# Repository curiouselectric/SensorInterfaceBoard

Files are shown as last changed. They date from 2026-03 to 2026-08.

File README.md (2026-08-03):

# Sensor Interface Board

A unit to interface various sensors (digital/analog/RS485) with a simple serial interface via an ATMega328-based circuit. The unit also provides averaged data, controlled stepped-up supply voltage and a field-adjustable ID.

"Why do you need that?", you ask.... 

I had been wanting to use an industrial soil mositure sensor for a simple project. This device was only available as an RS3485 device. So I ordered that - it then took days of head scratching to sort basic communication with the device. This unit is meant to simplify reading of avaeraged data from RS485 sensors and make it easy to get that data into your project via a simple serial request/reply set of commands.

The other issue with a lot of the RS485 sensor is that they need higher voltages supplied (such as 12V or even 24V DC). So on this interface board I added a DC-DC step up converter to power the sensor. 

I was also concerned with energy consumption (my project was battery based). If I was to leave the DC-DC converter running all the time then my battery would run down very quickly. So I added control of the power to the sensor, so that I can power up, take the readings then power down. This saves a huge ammount of energy (well, proportional to my battery size).

## Overview

The problem with measuring sensors with values that change relatively quickly is that they constantly need to be checked. This requires a bit of microcontroller time and processing. This unit is designed to solve that.

Wire up your RS485 sensor. Power the unit up. Then it will save the averaged data for you. You can then get hold of the data through serial requests and process as you need.

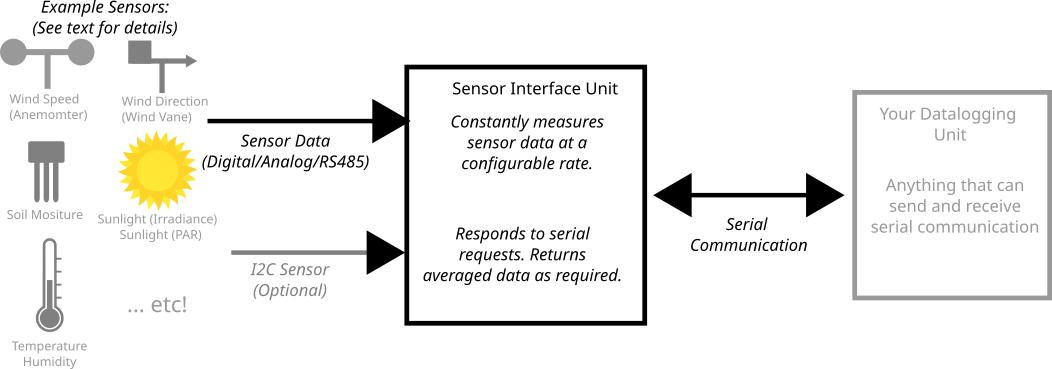
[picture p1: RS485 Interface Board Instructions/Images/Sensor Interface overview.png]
Overview


I wrote this to interface to an ESP32 data logger, which sleeps most of the time. It wakes up, talks to the RS485 sensor, gets the data it needs, then goes back to sleep, knowing the RS485 Interface Board is always monitoring.

It was designed as a relatively simple interface to remove the need for monitoring pulses/dealing with RS485 requests/getting sensor data and averaging the sensor data.

The brilliant [ESPHome project](https://esphome.io/components/#environmental) has loads of sensor types you can interafce easily with a low cost ESP microcontrollers. For systems that have WiFi and good power connections then that project is a good resource to use. This project is designed for very low power systems (battery based datalogging) and for situations where easy access to Wi-Fi is not available.

There are two mode of operation, depending upon your use case:

## Response Mode

In this mode then the unit responds to serial requests made. You ask the sensor for data and this is returned. It never sends anything unless asked.

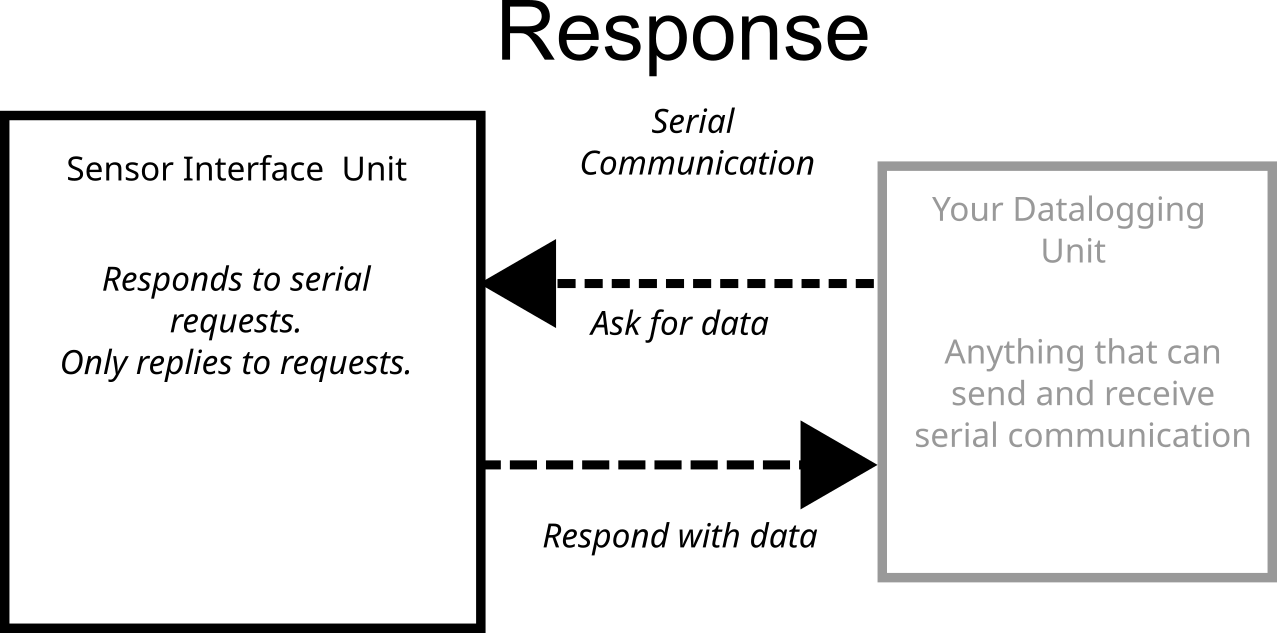
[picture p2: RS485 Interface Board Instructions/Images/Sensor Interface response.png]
Response


## Broadcast Mode

In this mode then the unit regularly sends data via the serial connunication. It will send the averaged data for (0) 1 second, (1) 10 second, (2) 1 min, (3) 10 min and (4) 1 hour averaged data. If this is set to (5) then the unit does not send any data. The send mode is stored in EEPROM, so it will start sending data again even if power is lost.

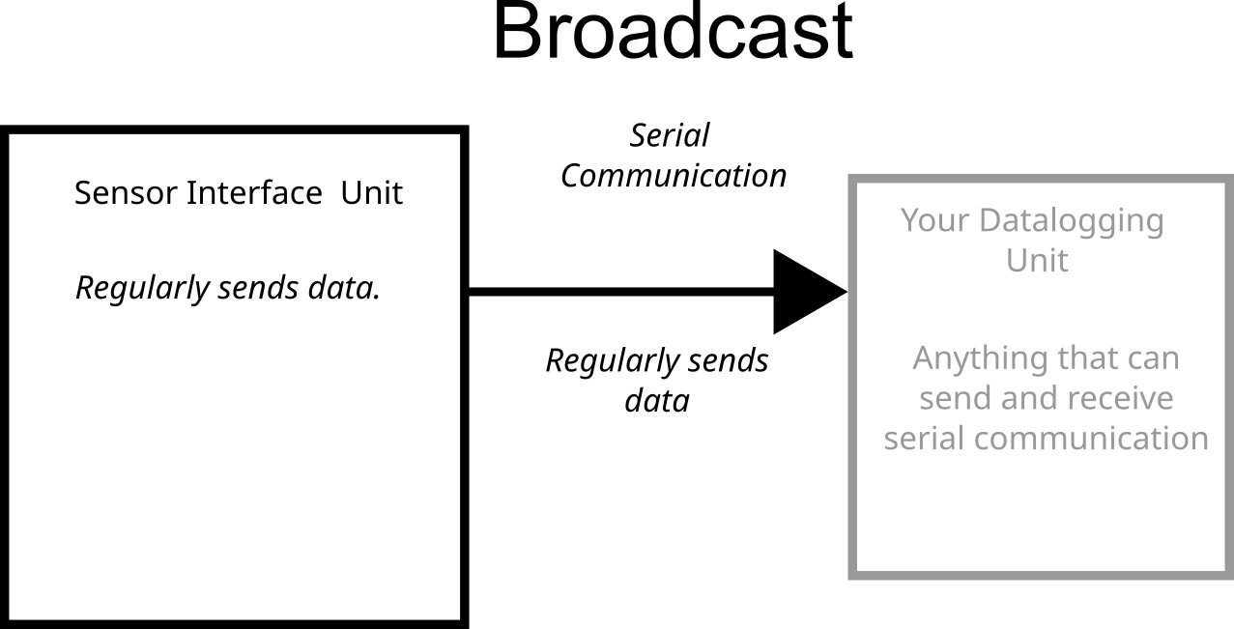
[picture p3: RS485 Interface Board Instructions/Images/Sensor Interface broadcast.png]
Broadcast


Boradcast mode works well if the logger is always listening and you only have one sensor in range. If more than one sensor is in range then the data will clash and potentially cause issues, in which case use Response mode.

The two modes work together - you can have the unit sending regular data and also responding to requests.

It runs on an ATMega328 running at 16MHz with selectable baud serial (up to 57600). It comes pre-programmed, but new code can be uploaded via the Arduino IDE, with the Uno bootloader. See firmware for more details.

## Sensor Types

There are a huge range of RS485 sensors for many different variables. I'd like this unit to be adaptable to work with a variety of sensors with minimal code changes.

This code base also works with other, non-RS485 sensors, such as wind speed sensors, wind vanes and solar irradiance sensors.

## Sensors Implemented:
This is a list of the sensor types which have been implemented with this software, Along with the version number they were added.

Sensor Name                        |  Ref    |  Version | Device Type  |   ID                   | Link                                                 | Notes  |
-----------------------------------|---------|----------|--------------|------------------------|------------------------------------------------------|--------|
Soil Temperature & Humidity        |ZTS-3000 |1.0       | SM           |ZTS-3000-TR-WS-N01     |[https://www.curiouselectric.co.uk/products/soil-moisture-sensor](https://www.curiouselectric.co.uk/products/soil-moisture-sensor) |     |
Wind Sensor (speed & direction)    |         |1.3       | WT           |                         |[https://www.curiouselectric.co.uk/collections/monitoring/products/wind-sensor-interface](https://www.curiouselectric.co.uk/collections/monitoring/products/wind-sensor-interface)  | Works with Anemometer and Wind Vane | 
RS485 Pyranometer Irradiance Sensor| PYR20    |1.4         | PY           |PYR20              |[https://www.aliexpress.com/item/1005002999915991.html](https://www.aliexpress.com/item/1005002999915991.html) |              |
DIY Irradiance Sensor              |         |          | IR           |                |     |     |
PAR Sensor                         |         |          | PR           |                |     |     |
Air Temperature/Humidity/Pressure  |         |1.3       | not needed    |AHT20 / BMP280 | [https://www.aliexpress.com/item/1005004460907148.html](https://www.aliexpress.com/item/1005004460907148.html) | This adds onto the PCB along with a sensor above|

# Hardware

A number of PCBs have been designed in KiCAD. This repository holds the RS485 sensor and is available here. A small PCB has been designed.

There is one reset switch, one user input switch and one LED output. 

There is a step-up DC-DC converter with power control (to power higher voltage sensors). 

There is a TTL to RS485 converter (to connect to the RS485 sensors)

There is a 4 pin 'Grove'-type connector for direct connection I2C (code for this is not yet implemented) 

## Board ID Number

Each unit can have a unique ID (using a push link 6 pin pad for 0-7 values), so multiple units can be added to a serial bus, if needed. The defalt is 0 (no links used).

## PCB User Switch and User LED

There is one user switch and one user LED on the unit.

The LED will show a regular flash every 5 seconds. This will briefly flash once every 5 seconds if the unit is in 'Response' mode. The LED will briefly flash twice every 5 seconds if the unit is in 'Broadcast' mode. Data will be sent at the broadcast rate.

The LED will also flash whenever data is sent of the serial port. The LED will go on before data sent and then off after data is sent.

Pressing the user switch for >0.5 seconds and then releasing will result in a switch press.

A switch press will increment the mode from 0-1-2-3-4-5 then back to 0.

The unit will flash after a button press to indicate the broadcast mode (so 0 flashes if the value is 0, 1 flash if the value is 1 etc).

If this is set to 5 then the unit works in 'Response' mode.

If this is set to 0-4 then the unit is in 'Broadcast' mode and will send the data at the relevant interval (0 = 1s, 1 = 10s, 2 = 1 min, 3 = 10 min and 4 = 1 hour).

The mode can also be set with a serial request, using the "Set the unit to broadcast:" method (see below).

# Firmware

This uses an ATMega328 with the MiniCore Bootloader. This uses an oscillator running at 16MHz for 5V supply or 8MHz for 3.3V supply. Check the correct oscillator is chosen when uploading.

## Initial bootloader installation:

You should not need to do this, as the unit should come with this already installed. This is just for information.

To upload a bootloader it then MiniCore is used:

Install MiniCore from here: https://github.com/MCUdude/MiniCore

Install the bootloader using an Arduino as an ISP. https://www.arduino.cc/en/Tutorial/BuiltInExamples/ArduinoISP

Wire up your arduino and an ISP 3x2 header pin onto the wind sensor PCB.

Choose the "ATMega328" option with the "External 8MHz Oscillator" set for the 3.3V version or "External 16MHz Oscillator" set for the 5V version, depending upon the crystal supplied.

The ATmega328 datasheet says that an 8MHz crystal should be used at 3.3V for reliable serial comms. YMMV. 

You can then use the 'Burn Bootloader' option within 'Tools' in the Arduino IDE. This will install the Minicore bootloader.

## Program via Arduino IDE

You can only do this when the bootloader is programmed (this will be programmed for versions supplied by me).

To program it then MiniCore is used:

Install MiniCore from here: https://github.com/MCUdude/MiniCore

Add to preferences and then board manager.

Choose the "ATMega328" option with the "External 8MHz Oscillator" set for the 3.3V version or "External 16MHz Oscillator" set for the 5V version, depending upon the crystal supplied.

The ATmega328 datasheet says that an 8MHz crystal should be used at 3.3V for reliable serial comms. YMMV. 

You can then upload code using the 6pin serial/FTDI interface on the board.

# Serial Data and Commands

It returns the average values and information when requested on serial port.

If the 8-bit CRC (Cyclic Redundancy Check) is used then each request must have a 2 char CRC added between the ? and # within these commands (labelled ^^ here).
For the responses, if no CRC enabled then the ?^^ within these commands is NOT returned. You must use the ? for a command, but the response will not contain it.

At all other times then the unit is asleep.

## Set the unit to broadcast:

Request: "aaI0SEND*?^^#" where * is an int (0)= 1s data, (1)= 10s data, (2)= 60s/1 min data, (3)= 600s/10 min data, (4)= 3600s/1hr data, (5)= NO data

Returns: "aaI0SEND*?^^#" + CRC if requested where * is an int (0)= 1s data, (1)= 10s data, (2)= 60s/1 min data, (3)= 600s/10 min data, (4)= 3600s/1hr data, (5)= NO data

You can also set the unit to broadcast using the user switch. Press the button for around 0.5s or more then release. This will go through the boradcast modes from 0-1-2-3-4-5 then back round to 0. The LED will flash the number of times for the setting (so send = 0 the unit will not flash, but data will appear within 1 second!).

If the unit is in broadcast mode then the minimum and maximum wind speeds and the wind vane data are all reset each time period.

## What is baud rate?:

Request: "aaI0BD?#" ("aaI0BD?dc#" with CRC)

Returns: "aI0BD9600?^^#"  // Where 9600 is the baud rate 

## Set Baud Rate:

Request: "aaI0STBD\*?^^#"  Where \* is (0)1200, (1)2400, (2)9600, (3)57600, (4)115200

Returns: "aaI0BD9600?^^#"   // Where 9600 is the baud rate + CRC if requested

## What is ID?:

Mentioned at start up of unit - it is hardware set... and cannot be changed in code.

ID selection is by using a shorting link on the pads labelled 1, 2 and 4. The default is for no pads to be connected and the ID is 0. This means the unit will respond to "I0" as the ID.

To change the ID to another number from 0-7 then use a shorting link on the pins to create a binay number. The connections are:

1    |2    |4     | ID
-------|-------|-------|----
NC     |NC     |NC     | 0
CONN |NC     |NC     | 1
NC     |CONN |NC     | 2
CONN |CONN |NC     | 3
NC     |NC     |CONN | 4
CONN |NC     |CONN | 5
NC     |CONN |CONN | 6
CONN |CONN |CONN | 7

You can request the ID:

Request: "aaI*ID?^^#"  The * value can be anything.

Returns: "aaIXID:X?^^#"   // Where X is the device ID + CRC if requested

## Request Data from ONE channel

Request: “aaI0R00A*?^^#” where 00 is the channel number (00, 01 etc) and * is the averaging period (* = 0 for 1 sec data, 1 for 10 sec data, 2 for 60 sec (1 min) data, 3 for 600 sec (10 min) data and 4 for 3600 sec (1 hr) data 

Returns:  "aaI0R00A*:123.40:123.40:123.40?^^#"  // This wil return the average data then : then the minimum value then : then the maxximum value.

## Request Data from ALL channels

Request: “aaI0RAAA3?^^#”

Returns: "aaI0RAAA1:123.40:567.80?^^#" where the first item of data is channel 0, the next is channel 1. This will depend upon the number of channels.

## Request ALL Minimum data

Request: “aaI0RMNA4?^^#”  - does not matter what averaging period. min/max are just the min/max seen at max data rate.

Returns: "aaI0RMN:123.40:567.80?^^#"  where the first item of data is channel 0, the next is channel 1. This will depend upon the number of channels.

## Request ALL Maximum data

Request: “aaI0RMXA0?^^#”  - does not matter what averaging period. min/max are just the min/max seen at max data rate.

Returns: "aaI0RMX:123.40:567.80?^^#"  where the first item of data is channel 0, the next is channel 1. This will depend upon the number of channels.

## Reset the Min and Max value:

The min and max of each channel are logged. These are reset if the data is sent in broadcast mode. If the unit is in Response mode then you need to reset the min/max when you have taken the data.

Request: "aaI0RESET?#" ("aaI0RESET?d9#" with CRC)

Returns: "aaI0RSTOK#"

## Request Temperature, Humidity and Pressure Data

This command can only be used if the I2C AHT20/BMP280 sensor is attached and has been defined in the code. Otherwise it will return an error.

You can call this at any time and the unit will request from the sensor. It is NOT averaged or requested at any other point.

The Temp and Humidity board is an AHT20 (with device ID 0x38) and a BMP280 is used to measure the air pressure (with device ID 0x77).

Request: "aaI0TEMP?^^#"  (^^ for the CRC)

Returns: "aaI0T$$.$$H$$.$P$$$$$$?^^#" (^^ for the CRC) and $$$ are the values (floats) for Temeprature in C and Reltive Humidity in % and Air Pressure in Pa.
Returns: "aaI0T-H-P-#" if the board is not connected or there is an issue wth one of the sensors.

## Serial 'Button' press

You can simulate a button press with a serial command. This might be useful for some logging applications

The command "aaI0SWA?^^#"  (Where ^^ is the CRC of the data before the ?) will act just like a button press. This is for control via a data logger serial port without access to the physical switch.

Request: "aaI0SWA?^^#" 

Returns: "aaSEND*?^^#", where * is the time interval to send data (0->1->2->3->4->5->0 etc, with 5 never sending)

## What is the software version?:

Request: "aaI0SWV?^^#"

Returns: "aaI0SWV:1.0?^^#" (where 1.0 is the software version)

## What is the device type?:

Request: "aaI0DT?^^#""

Returns: "aaI0DT:SM?^^#" where SM is the device type (SM = Soil Moisture) - check the sensor list for these 2 char codes.

## Add CRC check:

Within the config of the firmware a CRC (Cyclic Redundancy Check) can be added to the data (or not!).

Set this true using the flag in the config.h file:

  #define ADD\_CRC\_CHECK     true    // Use this to add CRC check to incomming and outgoing messages
  
This uses the CRC routines from Rob Tillaart, available here: https://github.com/RobTillaart/CRC

A 'CRC-8/SMBUS' is perfromed on the data and a 2 byte CRC code is added to all replys (and expected on all enquiries). This is added between a ? and # symbol.

If no CRC then the end char is a #.

For example: aaI0RESET?d9# has the CRC check d9 added to the reset request.

Remember: Capitalisation will affect the results: D is not the same as d!

You can use this online calculator to check your CRC: https://crccalc.com/ The type of CRC is CRC-8/SMBUS.

## Failure codes:

If data is not that length or does not have 'aa' and '#' at start/end then return with send "aaFAIL\*\*#" error code. All will have CRC on these codes, if requested.

+ "aaFAILCRC?^^#": CRC check fail
+  "aaFAILTL?^^#": String too long
+  "aaFAILID?^^#": Problem with ID
+  "aaFAILIDX?^^#": ID not correct to device
+  "aaFAILPE?^^#": No aa and # on the string
+  "aaFAILBD?^^#": Baud rate change fail
+  "aaFAILCN?^^#": Channel number requested is greater than channels existing
+  "aaFAILCMD?^^#": Command not recognised 

# Sensor Specific Commands
For each sensor type there are additional commands. These are only available if the unit is in the correct mode.
They are listed here.

## 'SM' RS485 Soil Mositure Sensor

There are no extra commands.

## 'PY' RS485 Pyranometer Irradiance Sensor

There are no extra commands.

## 'WS' Wind Speed Sensor (Vane and Anemometer)

### Wind Speed data:

Request: “aaI0WSA4#”  ("aaI0WSA4?19#" with CRC)  Where 0 is an ID from 0-7 set by solder on PCB. 4 is the averaging period (0=1s, 1=10s, 2 = 60s, 3 = 600s, 4=3600s)

Returns: "aaI0WSA4:3.00:5.67:1.23#"  // Where 4 is the averaging period, 3.00 is the data within the averaging period, 5.67 is the maximum and 1.23 is the minimum.

### Wind Speed data minimum:

Request: “aaI0RMN#” ("aaI0RMN?^^#" with CRC) - does not matter what averaging period. min/max are just the min/max seen.

Returns: "aaI0RMN:3.00#"  // Where 3.00 is the data + CRC if requested

### Wind Speed data maximum:

Request: “aaI0RMX#”  ("aaI0RMX?^^#" with CRC) - does not matter what averaging period. min/max are just the min/max seen.

Returns: "aaI0RMX:3.00#"  // Where 3.00 is the data + CRC if requested

### What is Anemometer conversion?:

Request: "aaI0WSCON#" ("aaI0WSCON?41#" with CRC)

Returns: "aaI0STWSCONm123.4c567.89#" (from stored values) + CRC if requested

### Set the Anemometer conversion:

Request: "aaI0WSSTm123.4c567.89#"  ("aaI0WSSTm123.4c567.89?38#" with CRC) Where 123.4 is the gradient and 567.89 is the constant (y=mx+c)

Returns: "aaI0STWSSETm123.4c567.89#" (set to the new values) + CRC if requested

Request: "aaI0WSSTm1c0#" or "aaI0WSSTm1c0?da#" with CRC to set m= 1 and c=0. This is useful for initial testing.

### Wind Vane data:

Request: “aaI0WV#”  ("aaI0WV?b4#" with CRC) Where 0 is an ID from 0-7 set by solder on PCB.

Returns:    The instantaneuous direction AND the direction array data

Returns:    "aaI0WV=W:0.00:0.00:0.00:0.00:0.00:0.00:62.00:0.00#" + CRC if requested

### Reset the max, min and wind vane array:

Request: "aaI0RESET#" ("aaI0RESET?d9#" with CRC)

Returns: "aaRESET#"

### Enter vane training mode:

Request: "aaI0VT?#" ("aaI0VT?af#" with CRC) OR long press of the button (>1 second) will enter this mode.

Returns: Enter the vane training routine - use button to go through the different directions and set the values.

The serial port will show which direction the vane should be pointing at.

Move the vane to this position and press the user switch (for around 0.5 seconds).

The serial port will show then next direction and will got N, NE, E, SE, S, SW, W, NW and then end.

The unit will also send "aaI0WVOK=NW" + CRC +"#" to report back which direction the unit is now being trained.

When it ends this data is stored within the unit and the direction 'bands' are recaluclated.

# Overview of Connections

To Do - Update with new PCB version wiring diagram

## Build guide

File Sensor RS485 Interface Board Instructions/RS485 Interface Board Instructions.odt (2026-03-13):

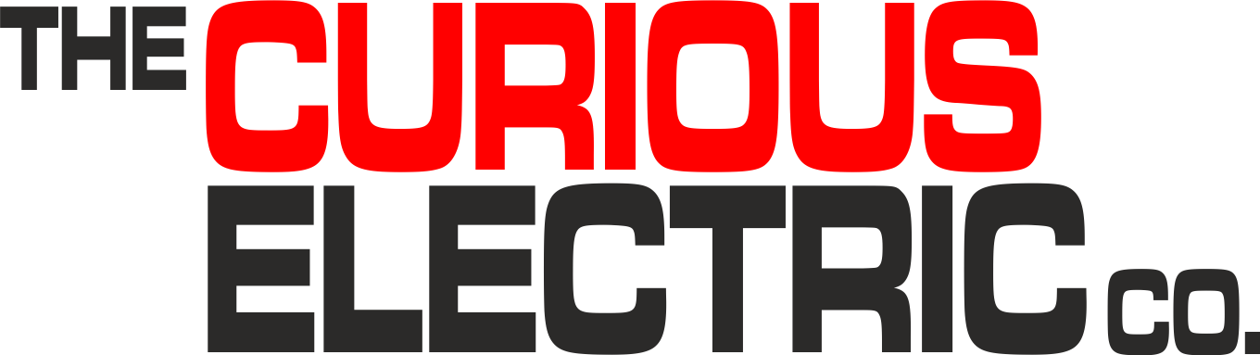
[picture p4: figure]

| RS485 Intrerface Board Instructions

Date: | 2/2/2026 | Version: | 1.0 | By: | Matt Little

This connects to various anemometers and wind vanes and provides a serial interface for averaged data from the pulses.

The problem with measuring wind anemometers and wind vane is that they constantly need to be checked. You need to always know when pulses have come in and which direction the wind vane is facing. This requires a bit of microcontroller time and processing.

This unit is designed to solve that. Wire up your vane and anemometer. Power the unit up. Then it will save the averaged data for you. You can then get hold of the data through serial requests and process as you need.

This unit can be ‘trained’ for your Wind Vane and the pulses converted into a real wind speed with a “Y = mX + c” conversion. The conversion values (m and c) can be adjusted for your anemometer.

All the firmware, unit operation and serial commands can be found here:

https://github.com/curiouselectric/WindSensor

# Parts included:

| | | 5 x 2 way Screw Terminals

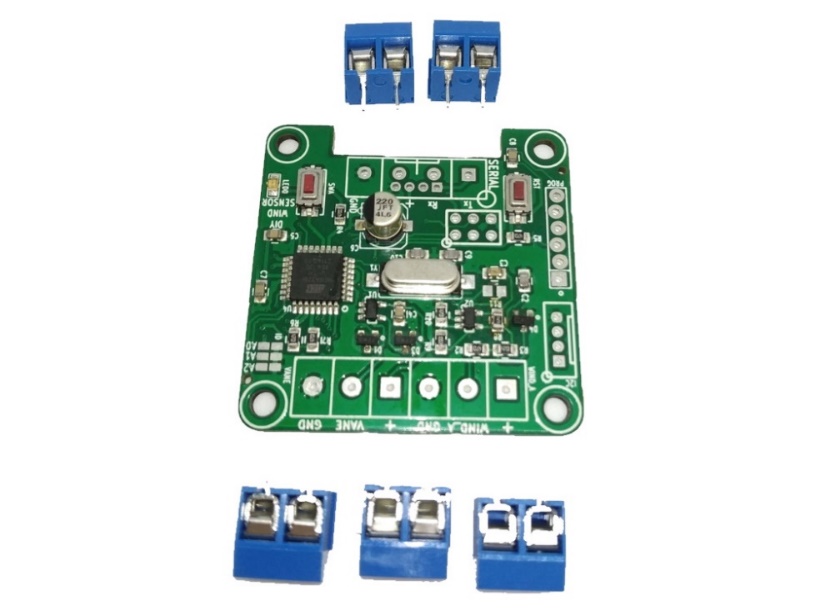
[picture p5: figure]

| | | | PCB with SMD components

# Parts list:

Item | Ref | Quantity
2 way screw terminals | | 5
PCB with all SMD components soldered | | 1

# Tools required:

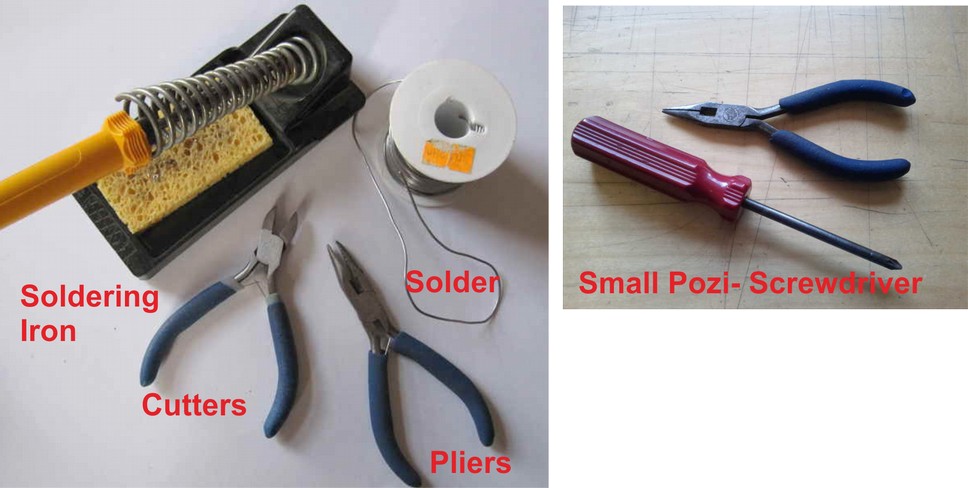
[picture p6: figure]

| | Long-nosed Pliers
Soldering Iron | | Posi-drive Screwdriver
Solder
Side cutters

Additional Items

- USB to 6 way ‘FTDI’ style serial converter:
  - Search for “FT232RL USB to TTL MiniUSB Port FTDI Serial Adapter Module for Arduino 5V 3.3V” on eBay
  - Or this FTDI one: https://ftdichip.com/products/ttl-232r-3v3/
  - You can also use an Arduino as a USB to serial converter.
- To update/change code: Computer with Arduino IDE and additional libraries installed. (see software section for more details).

Instructions:

Step: 1 | Solder Screw Terminals

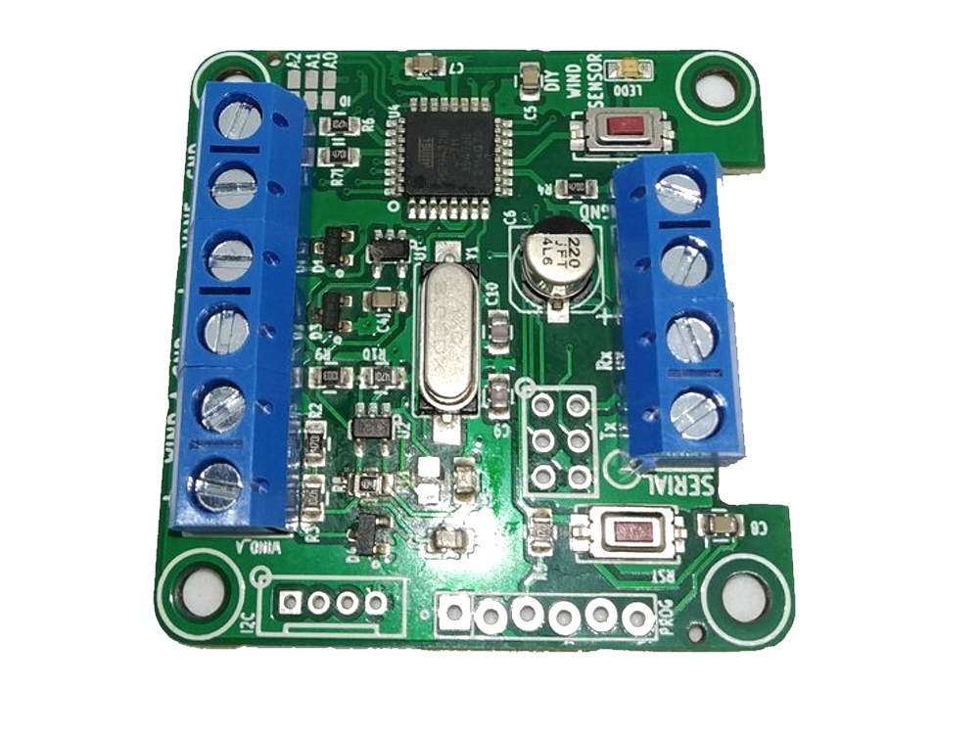
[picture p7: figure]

There are 5 2 way screw terminals to solder. Link two of them to make a 4 way connector and solder into the ‘serial’ connection. Link three of them and solder into the WIND_A and VANE connections, as shown. That’s all the soldering done!

Step: 2 | Set ID

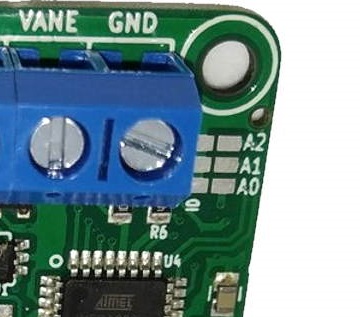
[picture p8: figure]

This step is not usually required. You can set the ID of the unit by connecting some pads with a solder blob. Solder according to this table. “Solder” means connect the two pads, “NC” means no connection. The default is 0. A0 A1 A2 ID NC NC NC 0 Solder NC NC 1 NC Solder NC 2 Solder Solder NC 3 NC NC Solder 4 Solder NC Solder 5 NC Solder Solder 6 Solder Solder Solder 7

Step: 3 | Wire up Anemometer

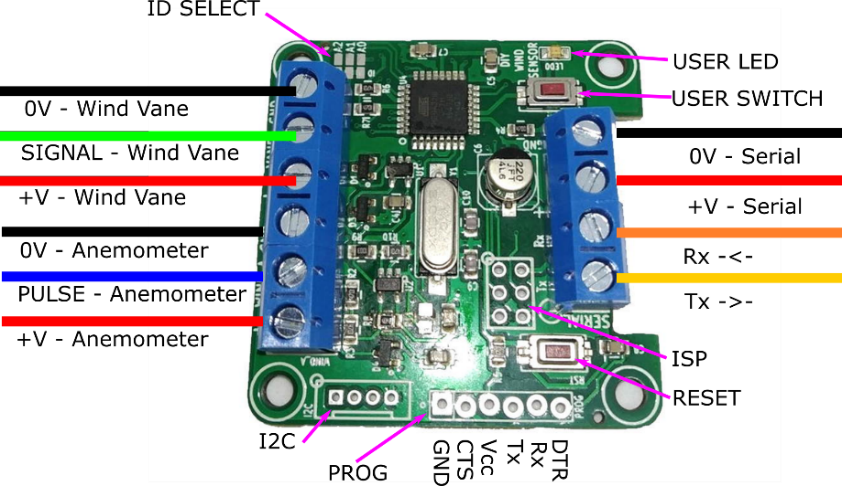
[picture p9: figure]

Wiring for this depends upon the type of anemometer: For switched pulse anemometers: connect the switch to 0V and to PULSE input, as there is a pull-up resistor. For NPN output anemometers: The +V will supply the Vcc to your anemometer. Typically, this is 3.3V or 5V. Wire this to the +ve of your anemometer. 0V is ground. Wire the NPN pulse output to PULSE. For Hall-Effect anemometers: Connect the output to the 0V and the PULSE input.

Step: 4 | Wire up Wind Vane

The wind vane wiring will also be different depending upon the type of vane.

For a resistive switched output vane, then you will need to use a 10k or 100k pull up resistor. Wire the vane output to 0V and SIGNAL. You can then either wire an external pull-up resistor to SIGNAL and +5V OR you can add a surface mount 0805-sized resistor onto the empty pad R12.

R12/pull-up resistor is simply a pull up resistor to the +V line, so choose the value according to your vane (typically 10k or 100k).

For potentiometer output vanes wire the 0V to one side of the variable resistor and the +5V for the other side of the variable resistor. The wire the wiper to SIGNAL.

Basically, you are trying to make a variable voltage input for the SIGNAL input.

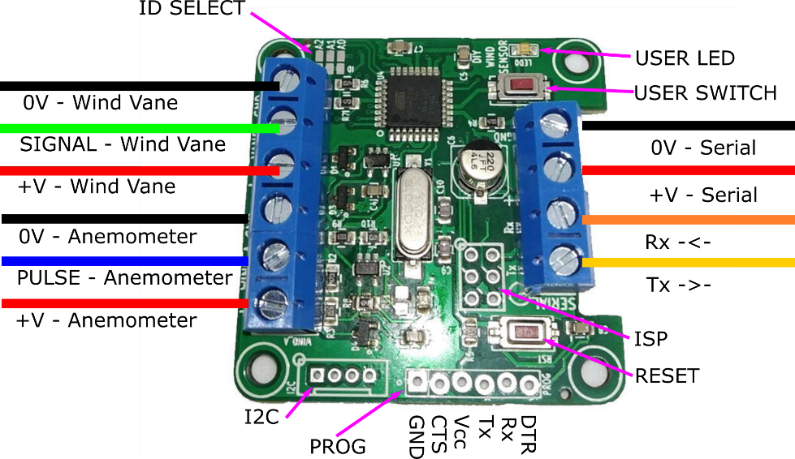
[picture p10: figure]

Step: 5 | PCB is finished!

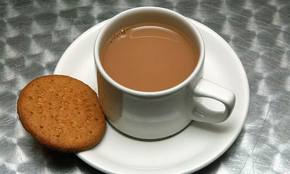
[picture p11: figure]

Have a nice cup of tea. | | That didn’t take long, did it?

Step: 6 | Connect to Arduino or USB-Serial Converter

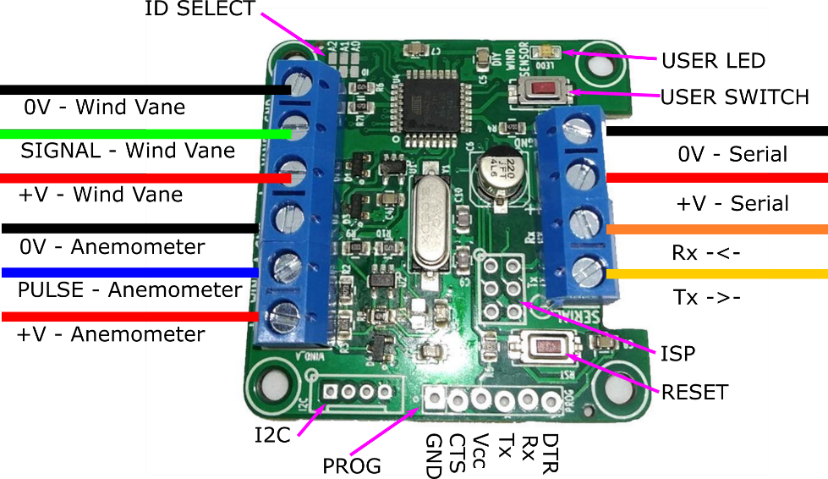
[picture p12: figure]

There is one main serial connector which has 0V, +V for the serial and also Rx and Tx. Upload a blank or ‘bare minimum’ sketch to an Arduino. You can wire your Arduino Tx to Rx and Rx to Tx. If you monitor the serial port at 9600 baud then you can send and receive responses. Follow the github examples and information for the most up to date information regarding the serial data and the functionality of the unit.

Step: 7 | Send Serial Commands
There are many serial commands that the unit can respond to. Please see: https://github.com/curiouselectric/WindSensor For the most recent information. This is kept online, so it can be easily updated.

Step: 8 | Write your own code
Everyone’s application is different, so this is where things get fun for your application! You need to think about what you would like from the unit. I have set up units that send out data at regular 1min outputs with a wireless transmitter. This used broadcast mode. I have also set up units that record the data to an SD card by using request mode.

Upload Firmware

This is not needed for standard use of the unit.

This can be where the fun begins! You can alter the code and improve it as you need.

This project has software stored on GITHUB software repository here:

https://github.com/curiouselectric/WindSensor

Please follow the readme in this repository for the most up to date instructions.

## Contact details:

This kit has been designed and produced by:

The Curious Electric Company

hello@curiouselectric.co.uk

www.curiouselectric.co.uk

We would like you to be happy with this kit. If you are not happy for any reason, then please contact us and we will help to sort it out.

Please email hello@curiouselectric.co.uk with any questions or comments.

Please tweet us at @curiouselectric

If any parts are missing from your kit, then please email hello@curiouselectric.co.uk with details, including when and where the kit was purchased.

More technical information can be found via www.curiouselectric.co.uk

# Circuit Schematic:

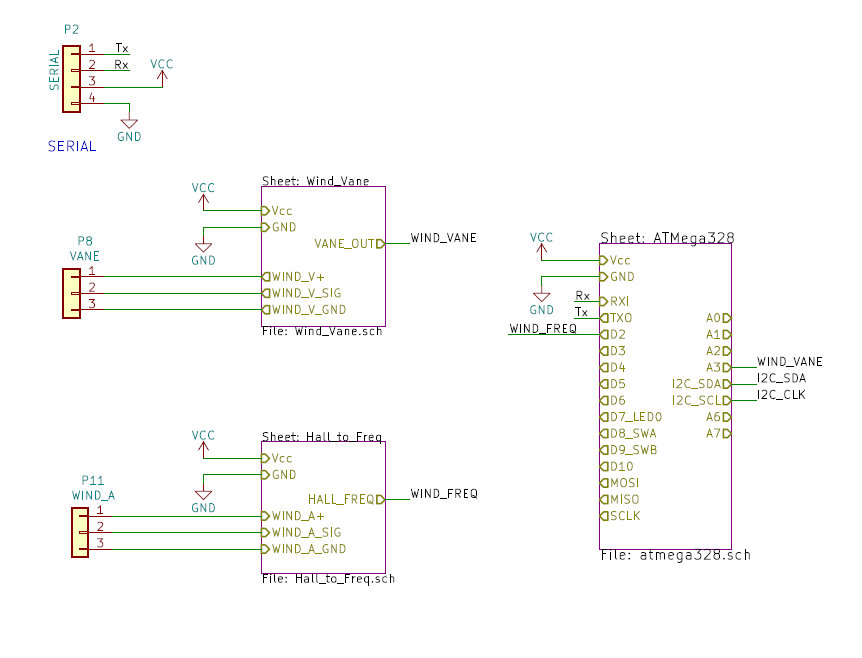
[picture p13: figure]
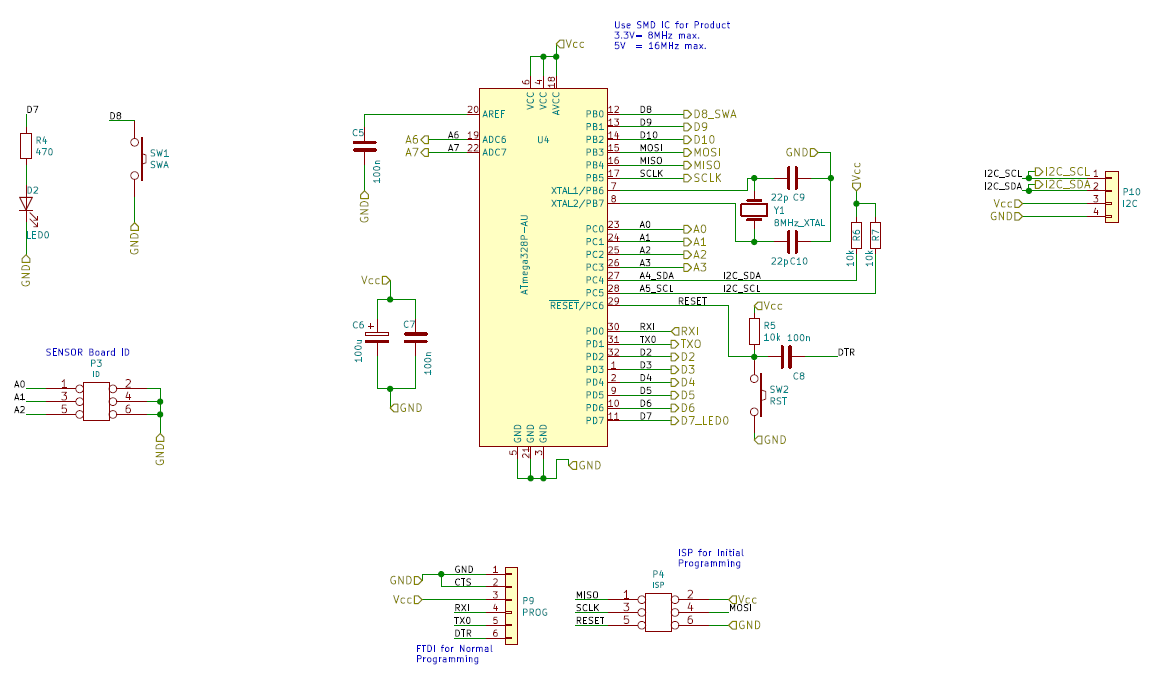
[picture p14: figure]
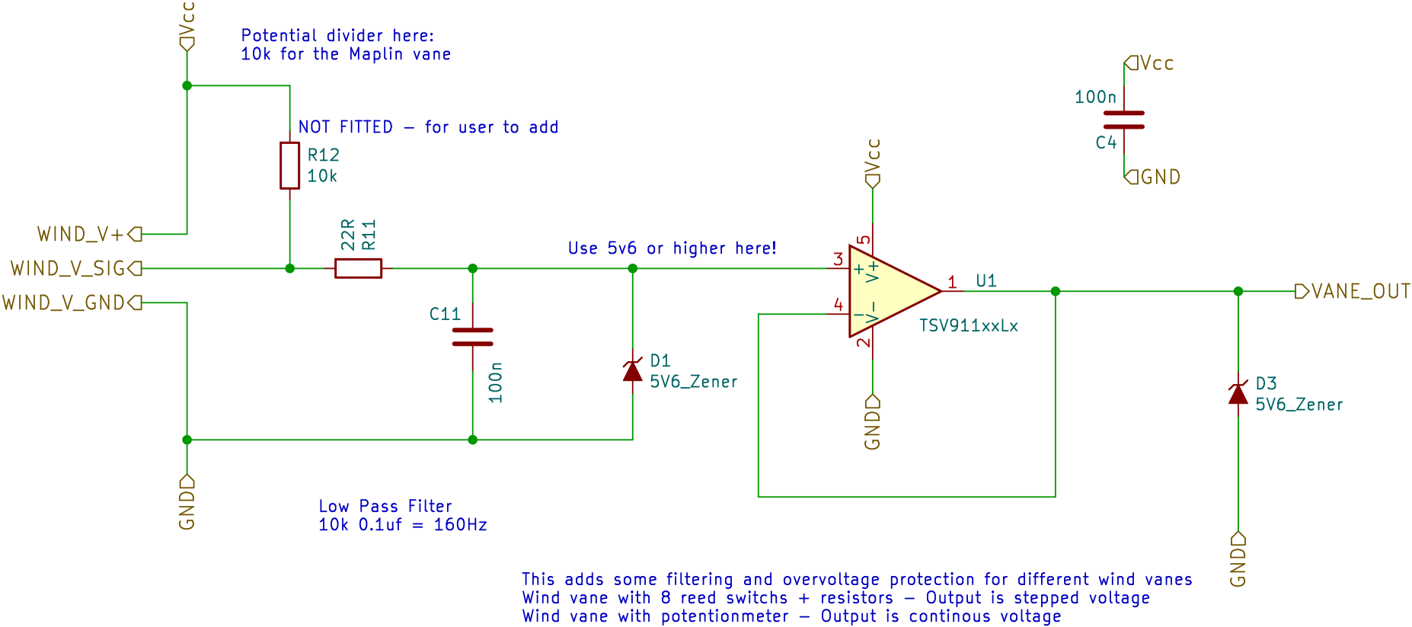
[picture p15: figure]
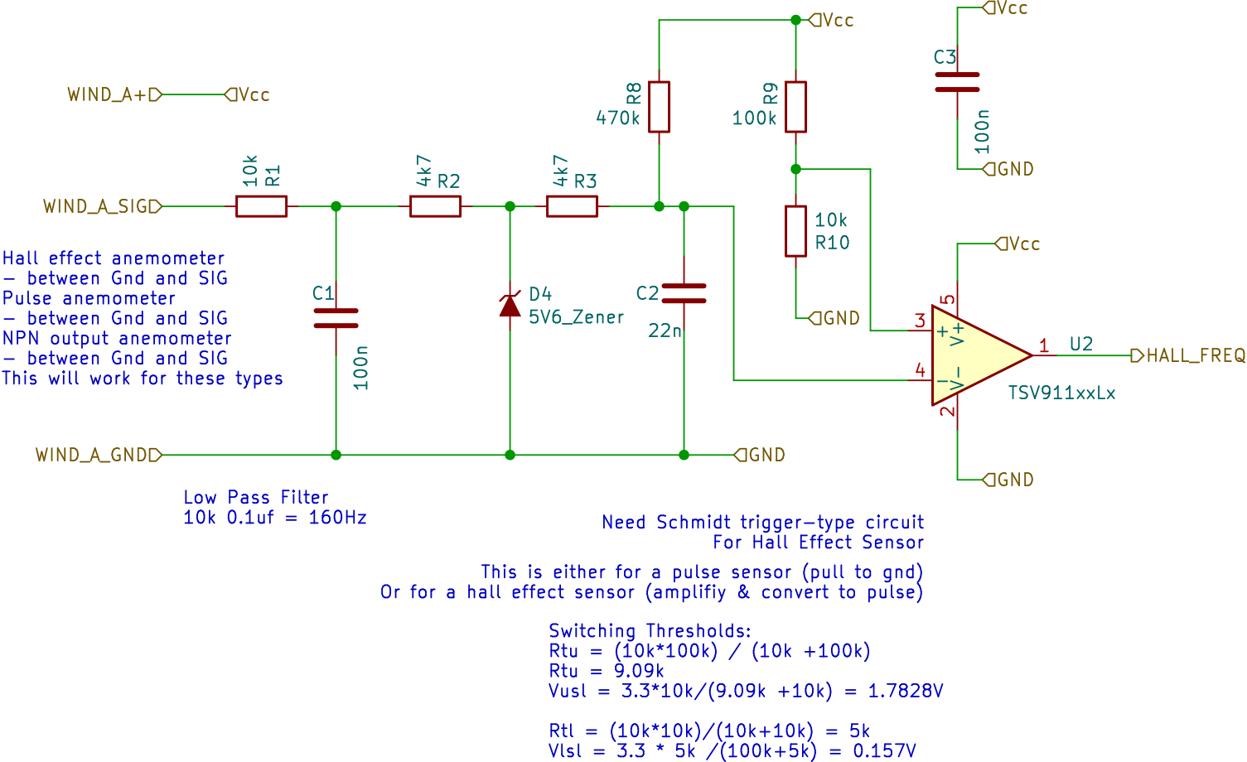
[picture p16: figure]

# PCB Design:

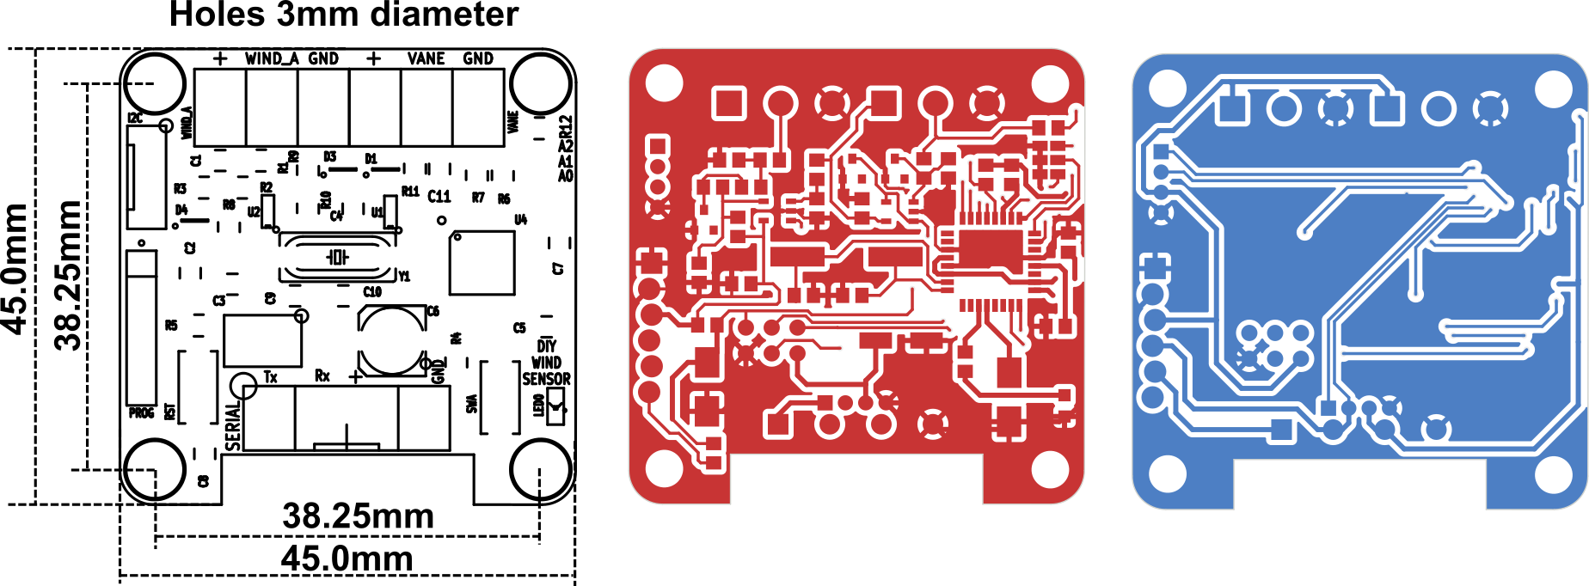
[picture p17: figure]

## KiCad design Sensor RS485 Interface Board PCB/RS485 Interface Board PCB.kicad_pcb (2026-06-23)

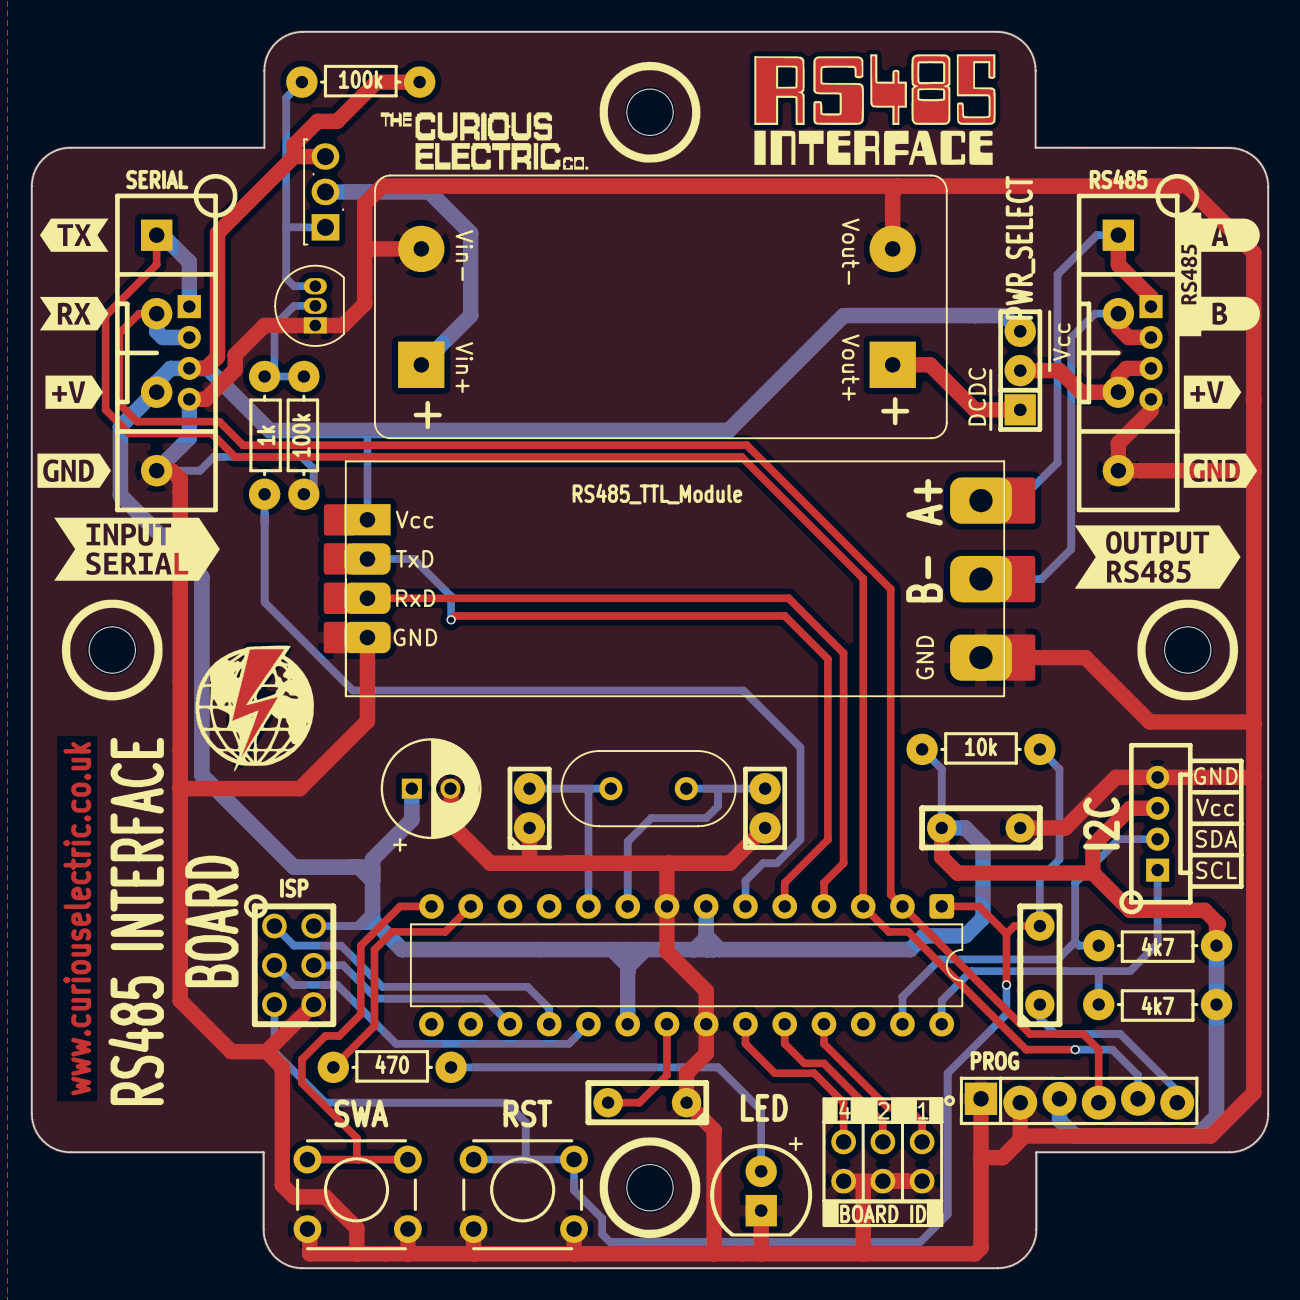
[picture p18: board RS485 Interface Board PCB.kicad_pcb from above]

Board: 2 copper layers, 80.0 x 80.0 mm, 44 parts (1 on the bottom side), 30 nets.

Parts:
C1, C3, C4: 100n; C1_wide_lg_pad_2
C2: 100u; C_Radial_D6.3_L11.2_P2.5
C5, C6: 22p; C1_lg_pad
D1: LED; TH_LED-5MM_AK
DCDC1: DC-DC_GENERIC; TH_DCDC_Step_up_MT3608
J1: PWR_SELECT; SIL-3_lg_pad_PWR_SELECT
P1: SERIAL; SIL-4_Grove_SCREW
P2: LOGO2; RS485 Logo Design
P3: PCB; PCB_outline_JSL22L
P5: I2C; SIL-4_Grove_Labelled_Correct
P6: RS485; SIL-4_Grove_SCREW
P7: BOARD ID; ID_SELECT_3x2
P8: PROG; TH_6x1_FTDI
P9: ISP; ISP_3x2
P10: LOGO3; TCEC_Words_13mm
P11: LOGO2; 2019_011_16_CuriousElectricCompany_Logo_Round_Logo_No_words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
Q1: 2N3904; TO-92_Inline
Q2: IRFR9220; TO-251-3_Vertical
R1: 1k; TH_Resistor_1
R2, R3: 100k; TH_Resistor_1
R4: 470; TH_Resistor_1
R5: 10k; TH_Resistor_1
R6, R7: 4k7; TH_Resistor_1
SW1: SWA; TH_FRONT_SW
SW2: RST; TH_FRONT_SW
U1: RS485_TTL_Module; TH_RS485_BI_SERIAL
U2: ATmega328P-P; DIP-28_W7.62mm
Y1: 8MHz_XTAL; Crystal_HC49-4H_Vertical
kibuzzard-68D6B9BB: G***; kibuzzard-68D6B9BB
kibuzzard-68D6B9C5: G***; kibuzzard-68D6B9C5
kibuzzard-68D6B99D: G***; kibuzzard-68D6B99D
kibuzzard-68D6B914: G***; kibuzzard-68D6B914
kibuzzard-68D6B946: G***; kibuzzard-68D6B946
kibuzzard-68D6B980: G***; kibuzzard-68D6B980
kibuzzard-68D6BA3C: G***; kibuzzard-68D6BA3C
kibuzzard-68D6BA4A: G***; kibuzzard-68D6BA4A
kibuzzard-68D6BA8E: G***; kibuzzard-68D6BA8E
kibuzzard-68D6BA98: G***; kibuzzard-68D6BA98
kibuzzard-68D6BAD1: G***; kibuzzard-68D6BAD1

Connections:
/ATMega328/A0: P7.5, U2.23 (PC0)
/ATMega328/A1: P7.3, U2.24 (PC1)
/ATMega328/A2: P7.1, U2.25 (PC2)
/ATMega328/D7: R4.1, U2.13 (PD7)
/ATMega328/D8: SW1.1, U2.14 (PB0)
/ATMega328/DTR: C4.1, P8.6
/ATMega328/MISO: P9.1, U2.18 (PB4)
/ATMega328/MOSI: P9.4, U2.17 (PB3)
/ATMega328/RESET: C4.2, P9.5, R5.2, SW2.1, U2.1 (~RESET/PC6)
/ATMega328/SCLK: P9.3, U2.19 (PB5)
/I2C_SCL: P5.1, R7.2, U2.28 (PC5)
/I2C_SDA: P5.2, R6.2, U2.27 (PC4)
/PWR_DC_DC: DCDC1.3 (+Vout), J1.1
/RS485_A: P6.1, U1.6 (A+)
/RS485_B: P6.2, U1.5 (B-)
/RS485_PWR: R1.2, U2.6 (PD4)
/RS485_Rx: U1.3 (Rx), U2.4 (PD2)
/RS485_Tx: U1.2 (Tx), U2.5 (PD3)
/Rx: P1.2, P8.4, U2.2 (PD0)
/Tx: P1.1, P8.5, U2.3 (PD1)
GND: C1.1, C2.2, C3.1, C5.1, C6.1, D1.1 (K), DCDC1.1 (-Vin), DCDC1.4 (-Vout), P1.4, P5.4, P6.4, P7.2, P7.4, P7.6, P8.1, P8.2, P9.6, Q1.1 (E), R2.1, SW1.2, SW2.2, U1.4 (GND), U2.8 (GND), U2.22 (GND)
unnamed: D1.2 (A), R4.2
unnamed: DCDC1.2 (+Vin), Q2.2 (D)
unnamed: J1.2, P6.3
unnamed: Q1.2 (B), R1.1, R2.2
unnamed: Q1.3 (C), Q2.1 (G), R3.1
unnamed: C1.2, U2.21 (AREF)
unnamed: C5.2, U2.9 (XTAL1/PB6), Y1.1
unnamed: C6.2, U2.10 (XTAL2/PB7), Y1.2
VCC: C2.1, C3.2, J1.3, P1.3, P5.3, P8.3, P9.2, Q2.3 (S), R3.2, R5.1, R6.1, R7.1, U1.1 (Vcc), U2.7 (VCC), U2.20 (AVCC)

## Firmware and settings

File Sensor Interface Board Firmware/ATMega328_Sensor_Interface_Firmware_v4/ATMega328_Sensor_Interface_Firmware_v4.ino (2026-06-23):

/*
    Sensor Interface firmware for ATMega328
   by:    Matt Little
   date:  25/02/2026
   w:     www.curiouselectric.co.uk
   e:     hello@curiouselectric.co.uk

   This code is for an ATMega328 sensor base unit. It is designed to read and average different sensors

   Different boards have been created:
   One (SensorInterfaceBoard) is designed to read RS485 sensor devices, store and average the data and then return the data based on simple serial commands.
   One (WindSensor) is designed for Wind speed sensors (anemometers) and Wind vanes
   One (Solar Sensor) is designed for Solar irradiance measurements.

   This uses an ATMega328 running at 8MHz (use this for 3.3V supply) or 16MHz (for 5V supply).

   It returns the average values when requested on serial port.
   Or it broadcasts wind speed and direction data at set intervals.
   A CRC check can be included on the serial data. - Set the ADD_CRC_CHECK flag to high.

   At all other times then the unit is asleep.

   This firmware is maintained in this repository:
   https://github.com/curiouselectric/SensorInterfaceBoard
   Please see the github rpository readme for all the serial commands available.


   More construction details, including PCB desings, are here:
   For the RS485 board:
   https://github.com/curiouselectric/SensorInterfaceBoard

   For the Wind Sensor Interface board:
   https://github.com/curiouselectric/WindSensor

   For the Solar Irradiance Board:
   https://github.com/curiouselectric/SolarSensor

   
    The ATMega382p IC can have Arduino Uno or MiniCore as the bootloader. MiniCore is slightly more efficient and allows the use of 8Mhz oscillator for 3.3V operation.
    Uno bootloader is always 16MHz.

   Wind Sensor intrafce has a 8MHz external clock - use minicore for this board:
   To program it with MiniCore bootloader:
   Easiest method is:
   Install MiniCore from here: https://github.com/MCUdude/MiniCore
   Add to preferences and then board manager.
   Use minicore to burn the bootloader with an Arduino as an ISP using the 'Burn Bootloader' option
   
   The Sensor interface board has an UNO bootloader and 16MHz external clock - use the UNO bootloader:
   To program with Uno bootloader:
   Follow online instructions or use Arduino as ISP.

    Things to do:


    Done:
    DONE 16/6/2026 - Add I2C reading of Temp and Humidity sensor (AHT20 and BMP280). Read this whenever the averaging period is (1, 10 60, 600, 3600 seconds).

*/

#include <stdio.h>
#include <Arduino.h>
#include <Wire.h>
#include <EEPROM.h>   // for saving mode to EEPROM
#include <avr/wdt.h>  // for the watch dog timer

#include "Button2.h"  // Need to include this to the library
#include "config.h"
#include "serial_parse.h"
#include "average_data.h"
#include "utilitiesDL.h"

#ifdef ADD_CRC_CHECK
#include "crc_check.h"
#endif

// ****** This is for the buttons button2 library used and needs to be installed ********
// https://github.com/LennartHennigs/Button2
Button2 buttonA = Button2(SWA_PIN);

// ******** This is for Scheduling Tasks **************************
// Must include this library from Arduino IDE Library Manager
// https://github.com/arkhipenko/TaskScheduler
#include <TaskScheduler.h>

// #define _TASK_TIMECRITICAL      // Enable monitoring scheduling overruns
#define _TASK_SLEEP_ON_IDLE_RUN  // Enable 1 ms SLEEP_IDLE powerdowns between tasks if no callback methods were invoked during the pass
// #define _TASK_STATUS_REQUEST    // Compile with support for StatusRequest functionality - triggering tasks on status change events in addition to time only
// #define _TASK_WDT_IDS           // Compile with support for wdt control points and task ids
// #define _TASK_LTS_POINTER       // Compile with support for local task storage pointer
// #define _TASK_PRIORITY          // Support for layered scheduling priority
// #define _TASK_MICRO_RES         // Support for microsecond resolution
// #define _TASK_STD_FUNCTION      // Support for std::function (ESP8266 and ESP32 ONLY)
// #define _TASK_DEBUG             // Make all methods and variables public for debug purposes
// #define _TASK_INLINE            // Make all methods "inline" - needed to support some multi-tab, multi-file implementations
// #define _TASK_TIMEOUT           // Support for overall task timeout
// #define _TASK_OO_CALLBACKS      // Support for dynamic callback method binding
// #define _TASK_DEFINE_MILLIS     // Force forward declaration of millis() and micros() "C" style
// #define _TASK_EXPOSE_CHAIN      // Methods to access tasks in the task chain

// Callback methods prototypes
void t1Callback();
void t1SCallback();
void t10SCallback();
void t60SCallback();
void t600SCallback();
void t3600SCallback();

// Tasks
// time (mS) between tasks, number of tasks to do, call back function
/*
  Scheduling defines:
  TASK_MILLISECOND
  TASK_SECOND
  TASK_MINUTE
  TASK_HOUR
  TASK_IMMEDIATE
  TASK_FOREVER
  TASK_ONCE
  TASK_NOTIMEOUT
*/

Task t1(100 * TASK_MILLISECOND, TASK_FOREVER, &t1Callback);  // Sample as base rate of 10Hz
Task t1S(TASK_SECOND, TASK_FOREVER, &t1SCallback);
Task t10S(10 * TASK_SECOND, TASK_FOREVER, &t10SCallback);
Task t60S(TASK_MINUTE, TASK_FOREVER, &t60SCallback);
Task t600S(10 * TASK_MINUTE, TASK_FOREVER, &t600SCallback);
Task t3600S(TASK_HOUR, TASK_FOREVER, &t3600SCallback);

Scheduler runner;

// *********** This is for the serial data parsing ******************
// Create a class for the serial data to be parsed
check_data checkData;

// *********** This is for the data holders *************************
// Want to create a data class for each channel, up to max of NUM_CHANNELS
data_channel my_sensor_data[NUM_CHANNELS];  // This creates our data channels
bool power_on_flag = false;                 // Use to check if sensor pwoered up or not

// *********** These are global variables ***************************
String inputString = "";      // a String to hold incoming data
String returnString = "";     // A string to hold the returned data
bool stringComplete = false;  // Checks if the string is complete

byte UNIT_ID = B00000000;  // This is the unit_id of the board itself. This will be default value. Values from 0-255 can potentially be used. 4 bit binary number? = 16 channels.

// Put LED flash into utilities to clean up code
//****************TO DO***************************
uint32_t led_flash_timer = millis();
bool led_update_flag = true;
uint8_t led_flash_counter = 0;  // Number of flashes to do

volatile int data_counter_1s = 0;
volatile int data_counter_10s = 0;
volatile int data_counter_60s = 0;
volatile int data_counter_600s = 0;
volatile int data_counter_3600s = 0;

#ifdef WIND_SENSOR
long int debounce_time = millis();
// *********** This is for the pulse counter ***********************
pulse_counter_ pulse_counter;
// // *********** This is for the wind vane ***********************
// wind_vane_array_ext    wind_vane_data;
//****ISR Function for pulse counting for wind speed************
void ISR_PULSE_0() {
  if (millis() > debounce_time + DEBOUNCE_DELAY) {
    pulse_counter.pulse_counter_1++;  // Increment the counter
    debounce_time = millis();
  }
}
#endif


void checkSensorData(int _channel_number) {
  // This checks  the data for the particular channel number depedning upon the data send time:
  switch (my_sensor_data[_channel_number].data_send_time) {
    case 0:
      my_sensor_data[_channel_number].data_1s_holder += getSensorData(_channel_number);
      break;
    case 1:
      my_sensor_data[_channel_number].data_1s = getSensorData(_channel_number);
      break;
    case 2:
      my_sensor_data[_channel_number].data_10s = getSensorData(_channel_number);
      break;
    case 3:
      my_sensor_data[_channel_number].data_60s = getSensorData(_channel_number);
      break;
    case 4:
      my_sensor_data[_channel_number].data_600s = getSensorData(_channel_number);
      break;
    case 5:
      my_sensor_data[_channel_number].data_3600s = getSensorData(_channel_number);
      break;
    default:
#ifdef DEBUG_FLAG
      Serial.println(F("aaDATAERR"));
#endif
      break;
  }
}

float getSensorData(int _channel_number) {
  // This routine actually gets the data from the device
  // This will depend upon the sensor attached
  float _data;

  // Power On if we want to check the data at this rate
  if (USE_RS485_POWER && !power_on_flag) {
    // Need to power up the sensor:
    digitalWrite(RS485_PWR_PIN, HIGH);
    delay(POWER_SETTLE_TIME);  // short settling delay
    power_on_flag = true;
  }

#ifdef SOIL_MOISTURE_SENSOR
  // get the data
  while (soilMoistureSensor.readHumiture(1) != true) {}
  if (_channel_number == 0) {
    _data = soilMoistureSensor.moisturePercent;
  } else if (_channel_number == 1) {
    _data = soilMoistureSensor.soilTemperatureC;
  }
#ifdef DEBUG_SOIL_MOISTURE
  Serial.print(F("M: "));
  Serial.print(soilMoistureSensor.moisturePercent);
  Serial.print(F(" %RH T: "));
  Serial.print(soilMoistureSensor.soilTemperatureC);
  Serial.println(F(" °C"));
#endif
#endif

#ifdef SOLAR_RS485_SENSOR
  // get the data
  while (pyr20SensorRS485.readIrradiance(1) != true) {}
  if (_channel_number == 0) {
    _data = pyr20SensorRS485.pyranInt;
  }
#ifdef DEBUG_SOIL_MOISTURE
  Serial.print(F("SW: "));
  Serial.print(_data);
    Serial.print(F(" W/m2"));
#endif
#endif


#ifdef WIND_SENSOR
  // Get the data
  if (_channel_number == 0) {
    _data = (float)pulse_counter.pulse_counter_1;  // Store it here, in case it updates during this analysis
  }
#endif

  // Power OFF if we have checked all the channels and the power was switched on
  if ((_channel_number == NUM_CHANNELS - 1) && power_on_flag == true) {
    if (USE_RS485_POWER) {
      digitalWrite(RS485_PWR_PIN, LOW);  // Switch off power
      power_on_flag = false;
    }
  }
  return (_data);
}


void t1Callback() {
  // This loop runs every 100mS
  // This will records the sensor value and store its it in the my_sensor_data array
  // Check the sensor for data, but only if config shows it should be checked at that rate:
  for (int j = 0; j < NUM_CHANNELS; j++) {
    if (my_sensor_data[j].data_send_time == 0) {
      checkSensorData(j);
    }
  }
#ifdef WIND_SENSOR
  uint16_t vane_value = analogRead(VANE_PIN);
  wind_vane_data.data_1s_holder += vane_value;
  wind_vane_data.build_direction_array(vane_value);
#endif

  // It will then be averaged for 1s, 10s, 60s 10min and 1 hour averages
  data_counter_1s++;  // This counts the correct number of samples we take within the 1S sample period. Used for averaging.
}

void t1SCallback() {
  if (!t1S.isFirstIteration()) {

    for (int j = 0; j < NUM_CHANNELS; j++) {
      if (my_sensor_data[j].data_send_time == 1) {
        checkSensorData(j);
      } else {
        // 1 second averages put into the correct channels
        my_sensor_data[j].data_1s = my_sensor_data[j].data_1s_holder / data_counter_1s;
        // reset all the data holders
        my_sensor_data[j].data_1s_holder = 0;  // Reset the value
      }

#ifdef WIND_SENSOR
      // Sort out the wind speed values
      // wind_speed_data.data_1s - convert as a y=mx+c
      if (my_sensor_data[j].data_1s > 0) {
        my_sensor_data[j].data_1s = (my_sensor_data[j].data_1s * my_sensor_data[j].wind_speed_conv_m) + my_sensor_data[j].wind_speed_conv_c;
      } else {
        my_sensor_data[j].data_1s = 0;  // This stops the unit outputting 'c' when there are no pulses
        // no pulses is assumed to be zero wind speed (we cannot infer anything else)
      }
      pulse_counter.pulse_counter_1 = 0;  // reset the value

      //  ********** Sort out the Wind Vane ***********************************
      wind_vane_data.data_1s = wind_vane_data.data_1s_holder / data_counter_1s;
      wind_vane_data.data_1s_holder = 0;  // Reset the holder
      // Convert the direction_array into average number of seconds in each direction:
      for (int y = 0; y < 8; y++) {
        wind_vane_data.direction_array_values[y] += (float)wind_vane_data.direction_array[y] / (float)data_counter_1s;
        wind_vane_data.direction_array[y] = 0;
      }
#endif
      // Here we set the max and min for the data
      if (my_sensor_data[j].data_1s < my_sensor_data[j].data_min) {
        my_sensor_data[j].data_min = my_sensor_data[j].data_1s;
      }
      if (my_sensor_data[j].data_1s > my_sensor_data[j].data_max) {
        my_sensor_data[j].data_max = my_sensor_data[j].data_1s;
      }
    }

    // Put all the data into the 10s average info
    for (int j = 0; j < NUM_CHANNELS; j++) {
      // Add on values for next average
      my_sensor_data[j].data_10s_holder += my_sensor_data[j].data_1s;  // This is for the 10s averages
    }

    if (checkData.send_sensor_data == 0) {
      sendData(0);
      reset_data();
    }

    // Every second we recheck the bits of the UNIT_ID
    UNIT_ID = check_unit_id(UNIT_ID);
    data_counter_10s++;
    data_counter_1s = 0;  // Reset the counter
  }
}

void t10SCallback() {
  if (!t10S.isFirstIteration()) {
    for (int j = 0; j < NUM_CHANNELS; j++) {
      if (my_sensor_data[j].data_send_time == 2) {
        checkSensorData(j);
      } else {
        my_sensor_data[j].data_10s = (float)my_sensor_data[j].data_10s_holder / (float)data_counter_10s;
        // reset all the data holders
        my_sensor_data[j].data_10s_holder = 0;  // Reset the value
        // Add on values for next average
        my_sensor_data[j].data_60s_holder += my_sensor_data[j].data_10s;  // This is for the 60S averages
      }
    }

    if (checkData.send_sensor_data == 1) {
      sendData(1);
      reset_data();
    }
    data_counter_60s++;
    data_counter_10s = 0;
  }
}

void t60SCallback() {
  if (!t60S.isFirstIteration()) {
    for (int j = 0; j < NUM_CHANNELS; j++) {
      if (my_sensor_data[j].data_send_time == 3) {
        checkSensorData(j);
      } else {
        my_sensor_data[j].data_60s = (float)my_sensor_data[j].data_60s_holder / (float)data_counter_60s;
        // reset all the data holders
        my_sensor_data[j].data_60s_holder = 0;  // Reset the value
        // Add on values for next average
        my_sensor_data[j].data_600s_holder += my_sensor_data[j].data_60s;  // This is for the 600S averages
      }
    }

    // Here we want to check if we are regularly sending the data and send if needed:
    if (checkData.send_sensor_data == 2) {
      sendData(2);
      reset_data();
    }
    data_counter_600s++;
    data_counter_60s = 0;
  }
}

void t600SCallback() {
  // 10 minute averages
  if (!t600S.isFirstIteration()) {
    for (int j = 0; j < NUM_CHANNELS; j++) {
      if (my_sensor_data[j].data_send_time == 4) {
        checkSensorData(j);
      } else {
        my_sensor_data[j].data_600s = (float)my_sensor_data[j].data_600s_holder / (float)data_counter_600s;
        // reset all the data holders
        my_sensor_data[j].data_600s_holder = 0;  // Reset the value
        // Add on values for next average
        my_sensor_data[j].data_3600s_holder += my_sensor_data[j].data_600s;  // This is for the 3600S averages
      }
    }

    // Here we want to check if we are regularly sending the data and send if needed:
    if (checkData.send_sensor_data == 3) {
      sendData(3);
      reset_data();
    }
  }
  data_counter_3600s++;
  data_counter_600s = 0;
}

void t3600SCallback() {
  // 1 hour averages

  if (!t3600S.isFirstIteration()) {
    // 1 hour averages
    for (int j = 0; j < NUM_CHANNELS; j++) {
      if (my_sensor_data[j].data_send_time == 5) {
        checkSensorData(j);
      } else {
        my_sensor_data[j].data_3600s = (float)my_sensor_data[j].data_3600s_holder / (float)data_counter_3600s;
        // reset all the data holders
        my_sensor_data[j].data_3600s_holder = 0;  // Reset the value
      }
    }

    // Here we want to check if we are regularly sending the data and send if needed:
    if (checkData.send_sensor_data == 4) {
      sendData(4);
      reset_data();
    }
  }
  data_counter_3600s = 0;
}


void tap(Button2& btn) {
  // In this routine we figure out which button has been pressed and deal with that:
  if (btn == buttonA) {

    if (btn.wasPressedFor() > 1000) {
#ifdef WIND_SENSOR
      wind_vane_data.vane_training_mode = !wind_vane_data.vane_training_mode;
      if (wind_vane_data.vane_training_mode == true) {
        Serial.println(F("VTENTER"));
        wind_vane_data.vane_training_direction = -1;  // So we are checking north first
      } else {
        Serial.println(F("VTLEAVE"));
      }
#endif
    }

#ifdef WIND_SENSOR
    // Check if we are in wind training mode?
    if (wind_vane_data.vane_training_mode == true) {
      // If this is the case then the button just goes through the different directions
      // Want to store the vane_direction value into EEPROM at the correct location:
      // We store the 1 second average here:
      wind_vane_data.write_direction_array(wind_vane_data.vane_training_direction, analogRead(VANE_PIN));
      // Then increment the counter (next direction)
      wind_vane_data.vane_training_direction++;
      // ****** Start of button press for datalogger
      // Need to give command saying button has been pressed (and which direction now in)
      returnString = F("aaI");
      returnString += (String)UNIT_ID;
      returnString += F("WVOK=");
      returnString += wind_vane_data.vane_directions[wind_vane_data.vane_training_direction];  // Print the instantaneous value of the wind vane as a direction
#ifdef ADD_CRC_CHECK
        // Add the CRC here: This adds the ? the CRC and the # to the end
      returnString = add_CRC(returnString);
#else
      returnString += F("#");
#endif

      Serial.println(returnString);
      Serial.println("");  // This is needed just to clear the serial buffer from noise.

      // ****** End of button press for datalogger
      if (wind_vane_data.vane_training_direction >= 8) {
        wind_vane_data.vane_training_direction = 0;
        wind_vane_data.vane_training_mode = false;
        // Need to figure out the bands again:
#ifdef DEBUG_FLAG
        wind_vane_data.begin(true);
#else
        wind_vane_data.begin(false);
#endif
        // Want to reset the wind vane direction data as previous will be wrong!
        wind_vane_data.reset_vane_direction_array();
        Serial.println(F("aaI0VTEND#"));
      }
      checkData.button_press_flag = false;
    } else {
#endif
      // If SWA pressed then increment the "send_sensor_data" from 0-1-2-3-4-5 and back to 0.
      // This means data will be shown at 1s/10s/60s/600s/3600s timescales.
      // In this case we start to send data at regular intervals.
      checkData.send_sensor_data++;
      if (checkData.send_sensor_data >= 6) {
        checkData.send_sensor_data = 0;
      }

      if (checkData.send_sensor_data != EEPROM.read(EEPROM_SEND_DATA)) {
        // Update the EEPROM only if it has changed
        EEPROM.write(EEPROM_SEND_DATA, checkData.send_sensor_data);
      }
      returnString = F("aaSEND");
      returnString += (String)checkData.send_sensor_data;
      if (checkData.button_press_flag == false) {
        // We only come here if its been a button press, not a serial button command
#ifdef ADD_CRC_CHECK
        returnString = add_CRC(returnString);
#else
      returnString += F("#");
#endif
        Serial.println(returnString);
      }
      // Also want to flash the LED to show what send mode the unit is in:
      for (int i = 0; i < checkData.send_sensor_data; i++) {
        digitalWrite(LED0_PIN, true);
        delay(150);
        digitalWrite(LED0_PIN, false);
        delay(250);
      }
      checkData.button_press_flag = false;  //Reset the flag
    }
#ifdef WIND_SENSOR
  }
#endif
}
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
void loop() {
  // Deal with schedules tasks
  runner.execute();
  // Check buttons for input
  buttonA.loop();

  // This flashes the LEDs as needed...
  flashLED(LED_FLASH_TIME);

  // feed the WDT
  wdt_reset();

  // Check for serial data
  if (stringComplete == true) {
    // This means we have had some data come in:
    // So parse it to find ID etc
    returnString = checkData.parseData(inputString, UNIT_ID, my_sensor_data);
    // Deal with any flags set:
    if (checkData.button_press_flag == true) {
      tap(buttonA);
    }
#ifdef ADD_CRC_CHECK  // Add the CRC if needed:
    returnString = add_CRC(returnString);
#else
    returnString += F("#");
#endif
    Serial.println(returnString);
    inputString = "";
    stringComplete = false;
  }
}

/*
  SerialEvent occurs whenever a new data comes in the hardware serial RX. This
  routine is run between each time loop() runs, so using delay inside loop can
  delay response. Multiple bytes of data may be available.
*/
void serialEvent() {
  while (Serial.available()) {
    // get the new byte:
    char inChar = (char)Serial.read();
    // add it to the inputString:
    inputString += inChar;
    // if the incoming character is a newline, set a flag so the main loop can
    // do something about it:
    if (inChar == '\n') {
      stringComplete = true;
    }
  }
}

void sendData(int average_time) {
  // Send data on main serial port:

#ifdef WIND_SENSOR
  returnString = checkData.showChannelData(average_time, UNIT_ID, my_sensor_data, true);
#else
  returnString = checkData.showChannelData(average_time, UNIT_ID, my_sensor_data);
#endif

#ifdef ADD_CRC_CHECK
  returnString = add_CRC(returnString);
#else
  returnString += F("#");
#endif
  Serial.println(returnString);
}

void reset_data() {
  for (int j = 0; j < NUM_CHANNELS; j++) {
    // Here we reset the max and min for the data
    my_sensor_data[j].data_min = 999999;
    my_sensor_data[j].data_max = -999999;
  }
#ifdef WIND_SENSOR
  wind_vane_data.reset_vane_direction_array();
#endif
}

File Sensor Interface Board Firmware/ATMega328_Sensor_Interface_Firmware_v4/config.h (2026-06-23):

#pragma once

#include <Arduino.h>
#include <Wire.h>

// Define which sensor the unit is connected to.
// Please see https://github.com/curiouselectric/RS485InterfaceBoard for list of options

//#define SOIL_MOISTURE_SENSOR    // For the solar moisture sensor
//#define PAR_SENSOR            // For the PAR (Photosynthetically Active Radiation) sensor
//#define WIND_SENSOR       // For the Wind Speed and Vane sensor
//#define SOLAR_IRRADIANCE_SENSOR   // For the DIY Solar Irradiance Sensor
#define SOLAR_RS485_SENSOR   // For the RS485 Solar Pyranometer

// Hardware Definitions
#define SOFTWARE_VERSION  "1.4" // Defines which version of software - to control updates if needed   

#define I2C_TEMP_HUMID    // set this if there is an I2C sensor attached for temperature and humidity (comment out if its not available)

#define LED0_PIN          7     // Indication LED
#define SWA_PIN           8     // On board user switch (can also be called by serial command)

#define RS485_PWR_PIN     4     // This is a power output for the RS485 port
#define RS485_TX_PIN      3     // This is a Tx (out) for the RS485 port
#define RS485_RX_PIN      2     // This is a Rx (in) for the RS485 port
#define POWER_SETTLE_TIME 50    // Time in mS to wait after power is applied before sending serial data and time to wait after data set before switching off power.

#define LED_FLASH_TIME    5000    // time in mS between LED flashes in normal operation
#define LED_ON_TIME       100      // time in mS of the flash length
#define LED_BLINK_TIME    250     // Time (in mS) between LED flashes when mode changes


// Serial Communication control:
#define MAX_BAUD_RATES      5       // Serial comms baud rates available are: (0) 1200, (1) 24800, (2)(Default) 9600, (3) 57600, (4) 115200 
const long int baud_rates[MAX_BAUD_RATES] = { 1200, 4800, 9600, 57600, 115200 };  // This holds the available baud rates
#define EEPROM_SERIAL_BAUD  4       // EEPROM location of serial baud rate value (1 byte)

// ******** add CRC check  ***************************************************************
//#define ADD_CRC_CHECK         // Define this to add CRC check to incomming and outgoing messages

// Sending data info
#define EEPROM_SEND_DATA      120    // EEPROM location of this value (1 byte)

#define INPUT_STRING_LENGTH   25
#define RETURN_STRING_LENGTH  100
#define DELIMITER             ":"
#define NO_DATA_CHAR          "-"
const String FAIL_STRING =    "aaFAIL";

// *******TO DO ************** Sort out Debug as a #ifdef  to save code space.
#define DEBUG_FLAG          // Use this for debugging. Not need for roll out.
        
// These three digital pins are for the Device ID selection:
#define  GPIO_ID0      A2  //  A0 Digital 4 on Arduino
#define  GPIO_ID1      A1  //  A1 Digital 5 on Arduino
#define  GPIO_ID2      A0  //  A3 Digital 6 on Arduino

// I2C Options
// I2C ADC is on standard I2C Pins: A4 (SDA) and A5 (SCL)


// Definitions for the Soil Mositure Sensor:
#ifdef SOIL_MOISTURE_SENSOR
#include "soil_moisture_rs485.h"
#define NUM_CHANNELS          2     // This will depends upon the sensor
#define SENSOR_TYPE           "SM"  // Soil Mositure
#define USE_RS485_POWER       true  // Use the step up converter - CHECK IT IS SET TO THE CORRECT VOLTAGE
//#define DEBUG_SOIL_MOISTURE   // Use this to set debug messages on/off
#define SENSOR_ID             1     // This is defined within the sensor itself
#define POWER_SETTLE_TIME     350    // Time in mS to wait after power is applied before sending serial data and time to wait after data set before switching off power.
#define MOISTURE_READ_S       2     // When to read the data from this sesnor (0 = 100mS, 1 = 1S, 2 = 10S, 3 = 60s, 4 = 600s, 5 = 3600s)  
#define TEMPERATURE_READ_S    2     // When to read the data from this sesnor (0 = 100mS, 1 = 1S, 2 = 10S, 3 = 60s, 4 = 600s, 5 = 3600s)  
#endif

// Definitions for the PAR RS485 Sensor
#ifdef PAR_SENSOR
#endif



// Definitions for the PYR20 Solar Pyrnaometer sensor RS485 Unit
#ifdef SOLAR_RS485_SENSOR
#include "solar_pyran_rs485.h"
#define NUM_CHANNELS          1       // This will depends upon the sensor
#define SENSOR_TYPE           "PY"    // Pyranometer
#define USE_RS485_POWER       true    // Use the step up converter - CHECK IT IS SET TO THE CORRECT VOLTAGE
//#define DEBUG_SOIL_MOISTURE         // Use this to set debug messages on/off
#define SENSOR_ID             1       // This is defined within the sensor itself
#define POWER_SETTLE_TIME     350     // Time in mS to wait after power is applied before sending serial data and time to wait after data set before switching off power.
#define PYRAN_READ_S          1       // When to read the data from this sesnor (0 = 100mS, 1 = 1S, 2 = 10S, 3 = 60s, 4 = 600s, 5 = 3600s)  
#endif
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

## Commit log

2026-02-27 Large update of new code. Working with RS485 soil moisture sensor
    [Hall_to_Freq.sch, RS485 Device Connector PCB.sch, Wind_Vane.sch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]
2026-03-13 large update of firmware
    Works as RS485 board and Wind Speed Sensor firmware
    [Hall_to_Freq.sch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]
2026-06-16 Added I2C Temp sensor to code
2026-06-23 update of firmware to work with I2C sensor
    [RS485 Device Connector PCB-B_Cu.gbr, RS485 Device Connector PCB-B_Mask.gbr, RS485 Device Connector PCB-B_Silkscreen.gbr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]
